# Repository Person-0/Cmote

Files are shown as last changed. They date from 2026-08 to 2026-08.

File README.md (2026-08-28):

# **Cmote**

A USB-C IR transmitter for controlling devices like ACs, TVs for when you're too lazy to find the remote and your smartphone does not have a built-in IR blaster. Built-in to a devboard powered by the Attiny1616 MCU.

# PCB
> View PCB Directory: [/PCB](./PCB)

Schematics:

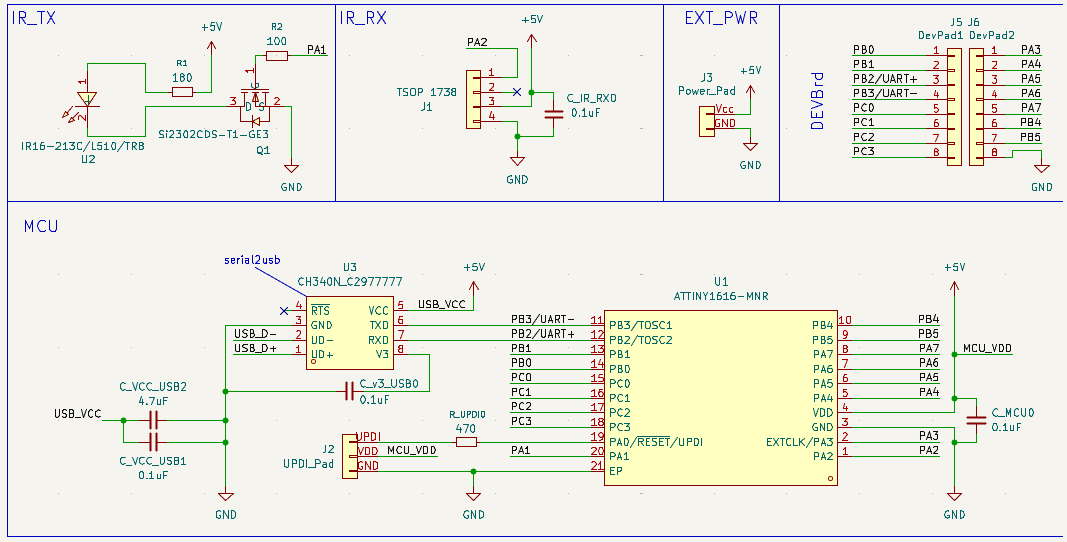
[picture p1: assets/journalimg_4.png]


PCB:

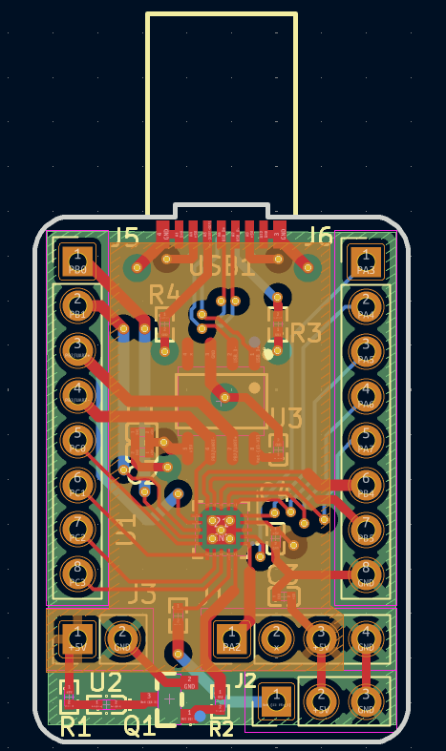
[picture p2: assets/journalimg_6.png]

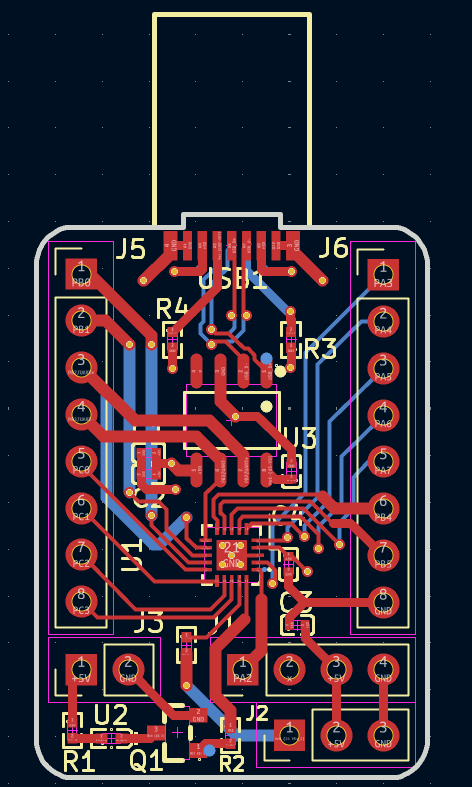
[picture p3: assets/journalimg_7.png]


Preview PCB 3D View:

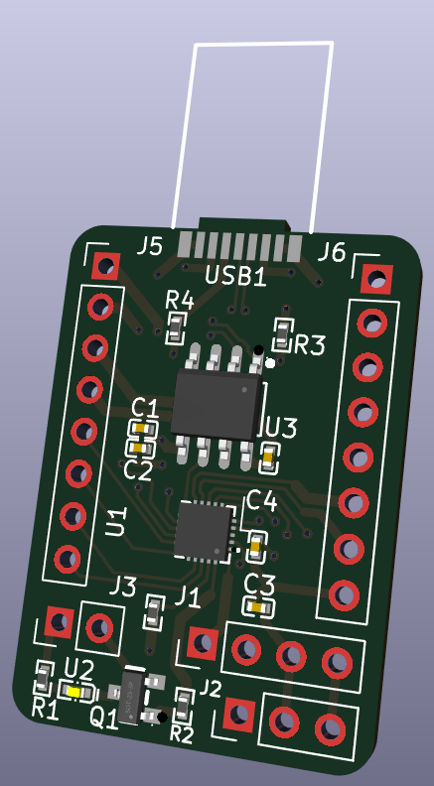
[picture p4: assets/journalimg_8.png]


Steps to open the schematics and PCB files in KiCAD:
- Open KiCAD
- Click **File** (top left) >> **Open Project**
- Navigate to this repository's saved destination,
- Open **/PCB/Cmote** directory
- Select the file `Cmote.kicad_pro`

This will open the schematics and PCB in KiCAD for easier viewing!

# Firmware
> View firmware directory: [/firmware](./firmware/)

> Note that firmware is Work In Progress. Until I physically receive the board I have no way of knowing whether this works or not so current it is just basic stuff.

The current firmware will send a power command at the start, listen to all the IR signals and print them to the serial on USB-C port of the board:

```cpp
bool sentPwrCmd = false;

void setup() {
	Serial.begin(115200); // serial is on usb-c
	IrSender.begin(IR_TX_PIN);
	IrReceiver.begin(IR_RX_PIN, ENABLE_LED_FEEDBACK); 
}

void loop() {

	if (!sentPwrCmd) {
		uint16_t address = 0x00; // standard device address
		uint8_t command = 0x45;  // standard power command
		IrSender.sendNEC(address, command, 0);
		sentPwrCmd = true;
		Serial.println("=== power command was sent!! ===");
	}

	if (IrReceiver.decode()) {
		Serial.println("-------------------------");
		Serial.println("\tbegin decode():");
        Serial.print("Protocol: ");
        Serial.println(getProtocolString(IrReceiver.decodedIRData.protocol));
        Serial.print("Command (Hex): 0x");
        Serial.println(IrReceiver.decodedIRData.command, HEX);
        Serial.print("Address (Hex): 0x");
        Serial.println(IrReceiver.decodedIRData.address, HEX);
        Serial.println("-------------------------\n");
        IrReceiver.resume(); 
    }

}
```

**IrReceiver and IrSender is from the [IRremote](https://registry.platformio.org/libraries/z3t0/IRremote) library.**

As for flashing the firmware onto the board, it requires a specialized UPDI programmer. However, I will be using another devboard to program this using **[pyupdi](https://github.com/mraardvark/pyupdi/)**. This guide will be updated after I test it myself to confirm what works and what does not.

# CAD
> View CAD Directory: [/CAD](./CAD)

While this is technically a devboard and has no requirement for a case, I still made one using Fusion360.

It looks like this:

> USB-C plug is invisible as no model was available for it from the manufacturer so I made sure to give enough space by measuring the silkscreen dimensions on the PCB and using it as the reference.

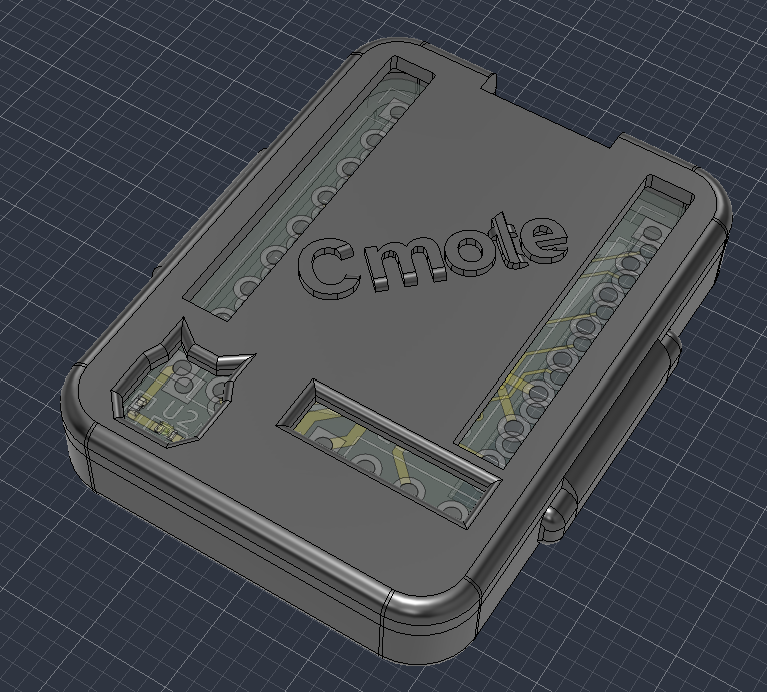
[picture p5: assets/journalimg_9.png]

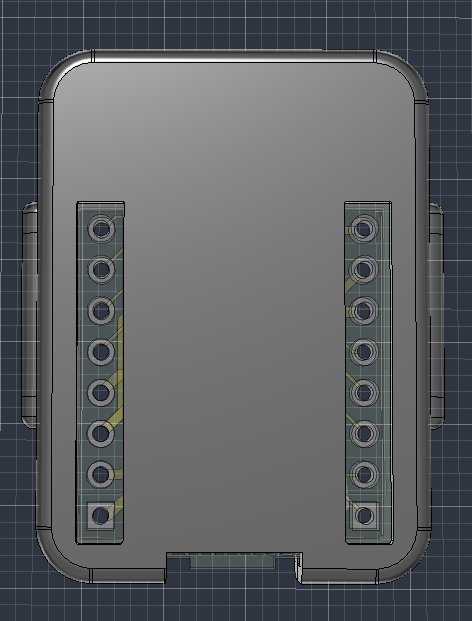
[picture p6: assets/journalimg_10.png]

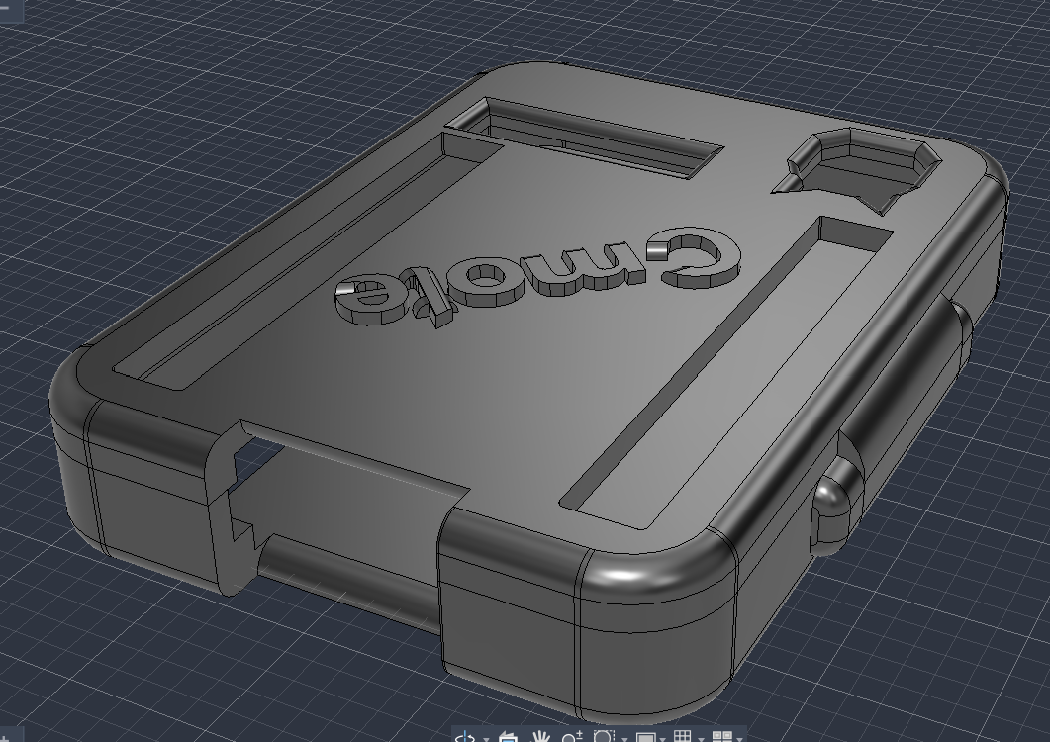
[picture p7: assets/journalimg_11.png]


The lid will friction fit into the case using the side extrusions.

It has rectangular cuts for headers so the devboard can be freely used without taking off the lid again and again.

**For 3d printing, files [Cmote_body.step](./CAD/Cmote_body.step) and [Cmote_lid.step](./CAD/Cmote_lid.step) need to be printed as different bodies.**

## Ordering Parts

I will be using JLCPCB to order my PCB as for my location it is the cheapest option (if using PCB Assembly service).

Please checkout the [JLC_Order](./PCB/JLC_Order/) directory for bom, cpl and gerber files.

The grand total for this project comes out to be at `42.24 USD`

- This is when I have used basic parts when possible and only 2 PCBA with 5 PCB (moq)

[View BOM](./bom.csv) <br>
[View PCBA BOM](./PCB/JLC_Order/pcb_bom.csv) <br>

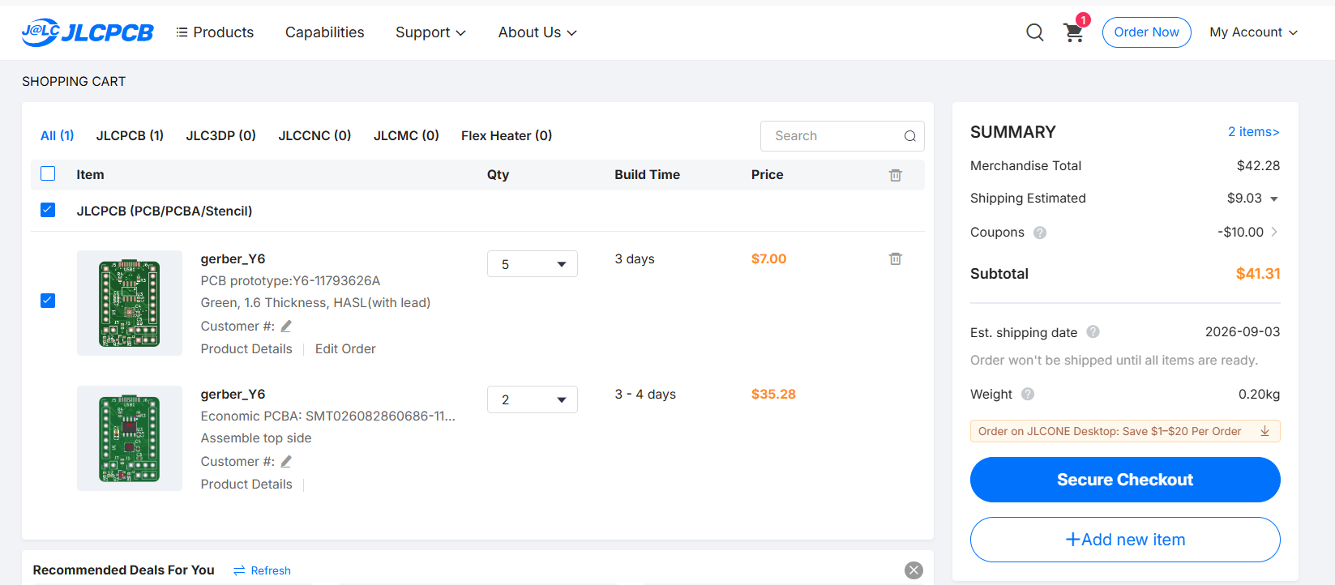
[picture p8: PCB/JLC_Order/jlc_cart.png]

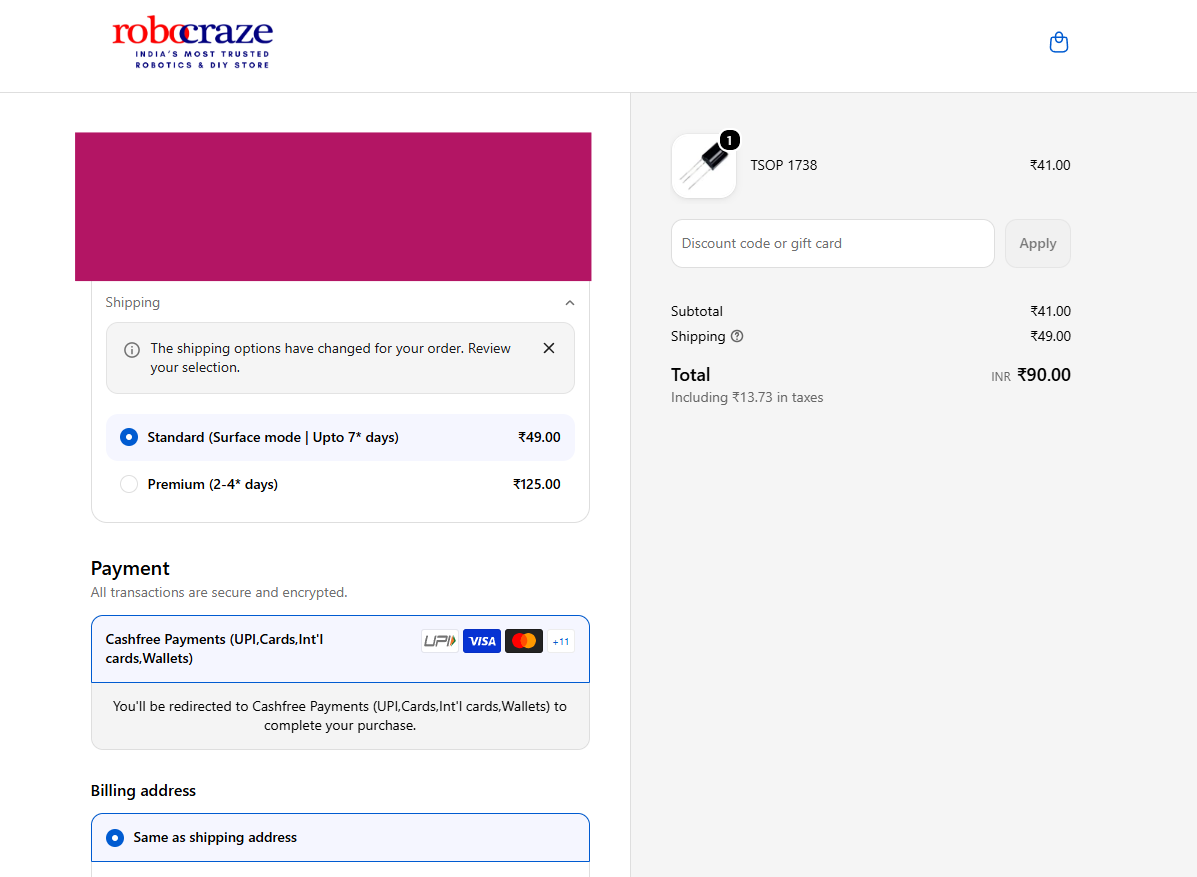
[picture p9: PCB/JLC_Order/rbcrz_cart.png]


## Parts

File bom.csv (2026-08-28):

 |  |  |  |  | $ | $
S.No | Name | Desc | Qty | Product URL | Cost Per Item | Effective Cost | Image
1 | JLCPCB_PCB | PCB | 1 | ~ | 7 | 7 | ./PCB/JLC_Order/jlc_cart.png
2 | JLCPCB_Assembly | PCB Assembly | 1 | ~ | 35.28 | 35.28
3 | JLCPCB_Shipping | Lowest price shipping: UPS Worldwide Express Saver | 1 | ~ | 9.03 | 9.03
4 | JLCPCB_Coupons | ~ | 1 | ~ | -10 | -10
5 | TSOP 1738 | IR Receiver Module | 1 | https://robocraze.com/products/tsop-1738?_pos=6&_sid=ae6cf2b3a&_ss=r | 0.43 | 0.43 | ./PCB/JLC_Order/rbcrz_cart.png
6 | Shipping for IR Receiver | Shipping for IR Receiver | 1 | https://robocraze.com/products/tsop-1738?_pos=6&_sid=ae6cf2b3a&_ss=r | 0.51 | 0.51
 |  |  |  |  | Total ($): | 42.25

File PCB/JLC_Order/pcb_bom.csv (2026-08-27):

Designator | Qty | Value | DNP | Exclude from BOM | Exclude from Board | Footprint | Datasheet | MPN | Manufacturer | LCSC Part | Description
C1 | 1 | 4.7uF |  |  |  | easyeda2kicad:C0402 | https://jlc-prod-smt.oss-eu-central-1.aliyuncs.com/smtDataManualFile/8579707103457972224-C19666.pdf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 | CL10A475KO8NNNC | Samsung Electro-Mechanics | C19666 | Unpolarized capacitor, small symbol
C2,C3,C4,C5 | 4 | 0.1uF |  |  |  | easyeda2kicad:C0402 | https://jlc-prod-smt.oss-eu-central-1.aliyuncs.com/smtDataManualFile/8579707269992677376-C1525.pdf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 | CL05B104KO5NNNC | Samsung Electro-Mechanics | C1525 | Unpolarized capacitor, small symbol
J1 | 1 | TSOP 1738 |  | Excluded from BOM |  | Connector_PinHeader_2.54mm:PinHeader_1x04_P2.54mm_Vertical | ~ |  |  |  | Generic connector, single row, 01x04, script generated (kicad-library-utils/schlib/autogen/connector/)
J2 | 1 | UPDI_Pad |  | Excluded from BOM |  | Connector_PinHeader_2.54mm:PinHeader_1x03_P2.54mm_Vertical | ~ |  |  |  | Generic connector, single row, 01x03, script generated (kicad-library-utils/schlib/autogen/connector/)
J3 | 1 | Power_Pad |  | Excluded from BOM |  | Connector_PinHeader_2.54mm:PinHeader_1x02_P2.54mm_Vertical | ~ |  |  |  | Generic connector, single row, 01x02, script generated (kicad-library-utils/schlib/autogen/connector/)
J5 | 1 | DevPad1 |  | Excluded from BOM |  | Connector_PinHeader_2.54mm:PinHeader_1x08_P2.54mm_Vertical | ~ |  |  |  | Generic connector, single row, 01x08, script generated (kicad-library-utils/schlib/autogen/connector/)
J6 | 1 | DevPad2 |  | Excluded from BOM |  | Connector_PinHeader_2.54mm:PinHeader_1x08_P2.54mm_Vertical | ~ |  |  |  | Generic connector, single row, 01x08, script generated (kicad-library-utils/schlib/autogen/connector/)
Q1 | 1 | Si2302CDS-T1-GE3 |  |  |  | easyeda2kicad:SOT-23_L2.9-W1.3-P1.90-LS2.4-BR | https://lcsc.com/product-detail/MOSFET_VISHAY_Si2302CDS-T1-GE3_Si2302CDS-T1-GE3_C10488.html | Si2302CDS-T1-GE3 | VISHAY(威世) | C10488 | Si2302CDS-T1-GE3
R1 | 1 | 180 |  |  |  | easyeda2kicad:R0402 | https://jlc-prod-smt.oss-eu-central-1.aliyuncs.com/smtDataManualFile/8755534832674197504-C137913.pdf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 | RC0402JR-07180RL | YAGEO | C137913 | Resistor, small symbol
R2 | 1 | 100 |  |  |  | easyeda2kicad:R0402 | https://jlc-prod-smt.oss-eu-central-1.aliyuncs.com/smtDataManualFile/8579705907476807680-C25076.pdf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 | 0402WGF1000TCE | UNI-ROYAL(Uniroyal Elec) | C25076 | Resistor, small symbol
R3,R4 | 2 | 5.1k |  |  |  | easyeda2kicad:R0402 | https://jlc-prod-smt.oss-eu-central-1.aliyuncs.com/smtDataManualFile/8579706035999215616-C25905.pdf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 | 0402WGF5101TCE | UNI-ROYAL(Uniroyal Elec) | C25905 | Resistor, small symbol
R_UPDI0 | 1 | 470 |  |  |  | easyeda2kicad:R0402 | https://jlc-prod-smt.oss-eu-central-1.aliyuncs.com/smtDataManualFile/8579705913225035776-C25117.pdf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 | 0402WGF4700TCE | UNI-ROYAL(Uniroyal Elec) | C25117 | Resistor, small symbol
U1 | 1 | ATTINY1616-MNR |  |  |  | easyeda2kicad:QFN-20_L3.0-W3.0-P0.40-BL-EP1.7 | https://lcsc.com/product-detail/MICROCHIP_Microchip-Tech-ATTINY1616-MNR_C507118.html | ATTINY1616-MNR | MICROCHIP(美国微芯) | C507118
U2 | 1 | IR16-213C/L510/TR8 |  |  |  | easyeda2kicad:LED0402-FD_YELLOW | https://www.lcsc.com/datasheet/C2943465.pdf | IR16-213C/L510/TR8 | EVERLIGHT(亿光) | C2943465
U3 | 1 | CH340N_C2977777 |  |  |  | easyeda2kicad:SOP-8_L4.9-W3.9-P1.27-LS6.0-BL | https://www.lcsc.com/datasheet/C2977777.pdf | CH340N | WCH(南京沁恒) | C2977777
USB1 | 1 | HYCW671-USBC14-115B |  |  |  | easyeda2kicad:USB-SMD_HYCW671-USBC14-115B | https://www.lcsc.com/datasheet/C53436581.pdf | HYCW671-USBC14-115B | HOAUC(华宇创) | C53436581

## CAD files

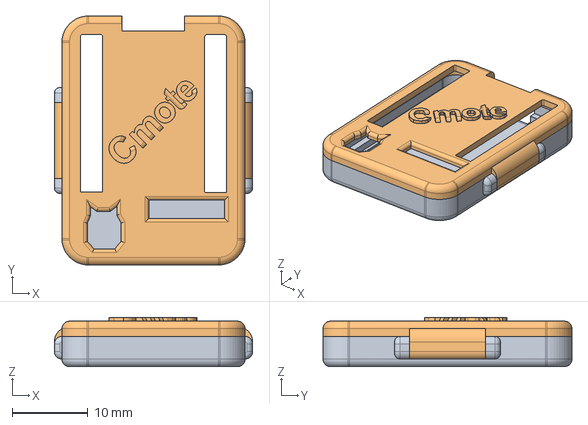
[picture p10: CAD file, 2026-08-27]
CAD/Cmote_full_DoNotPrint.step
26.2 x 32.9 x 6.50 mm

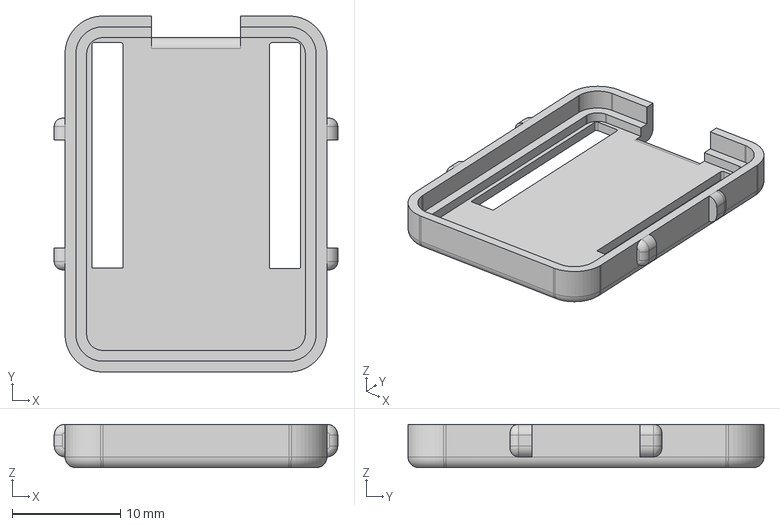
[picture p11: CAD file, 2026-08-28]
CAD/Cmote_body.step
26.2 x 32.9 x 4.00 mm

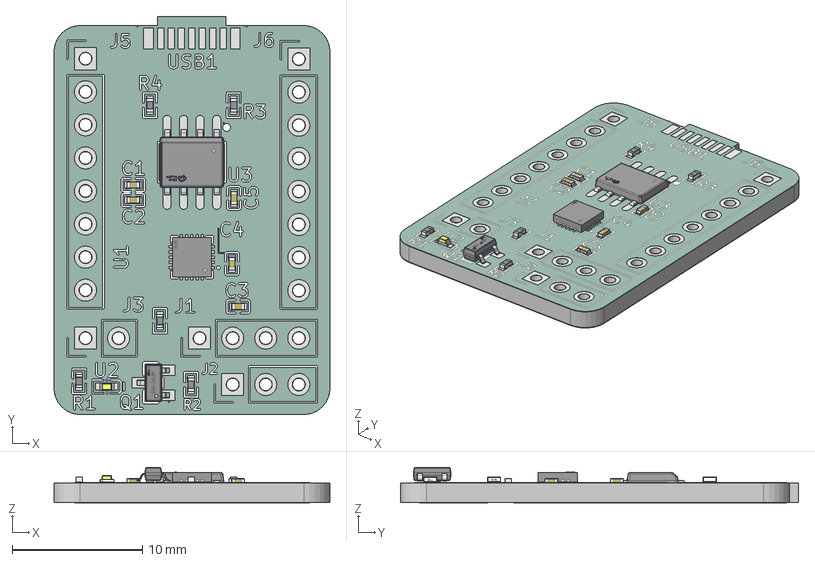
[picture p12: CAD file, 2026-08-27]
CAD/models/CmotePCB.step
21.2 x 30.6 x 2.77 mm
LED0402-FD_YELLOW
C0402_L1.0-W0.5-H0.5 x 5
R0402_L1.0-W0.5-H0.4 x 5
QFN-20_L3.0-W3.0-P0.40-BL-EP1.7
SOP-8_L4.9-W3.9-P1.27-LS6.0-BL-1
SOT-23-3P_L2.9-W1.3-H1.0-LS2.4-P0.95
Cmote_copper
Cmote_pad
Cmote_via
Cmote_silkscreen x 2
Cmote_soldermask x 2
Cmote_PCB

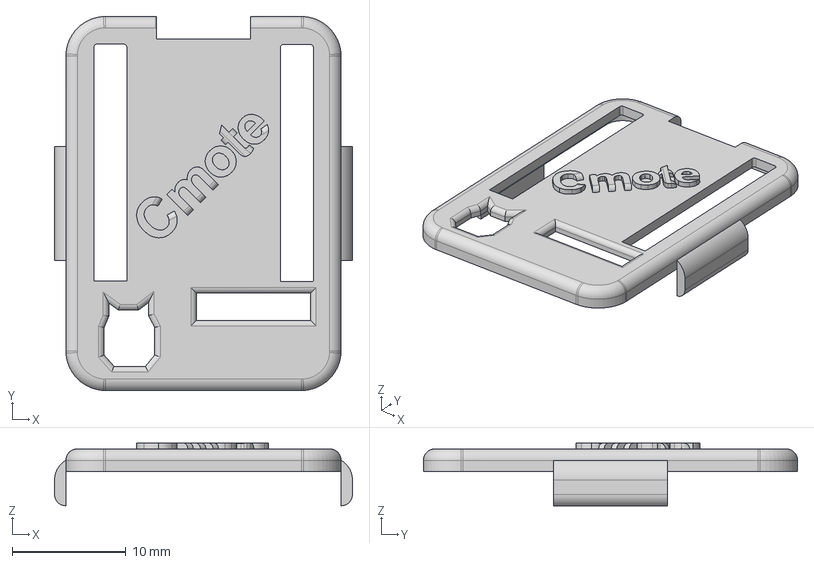
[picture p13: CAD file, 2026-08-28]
CAD/Cmote_lid.step
26.2 x 32.9 x 5.50 mm

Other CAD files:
CAD/Cmote.f3d

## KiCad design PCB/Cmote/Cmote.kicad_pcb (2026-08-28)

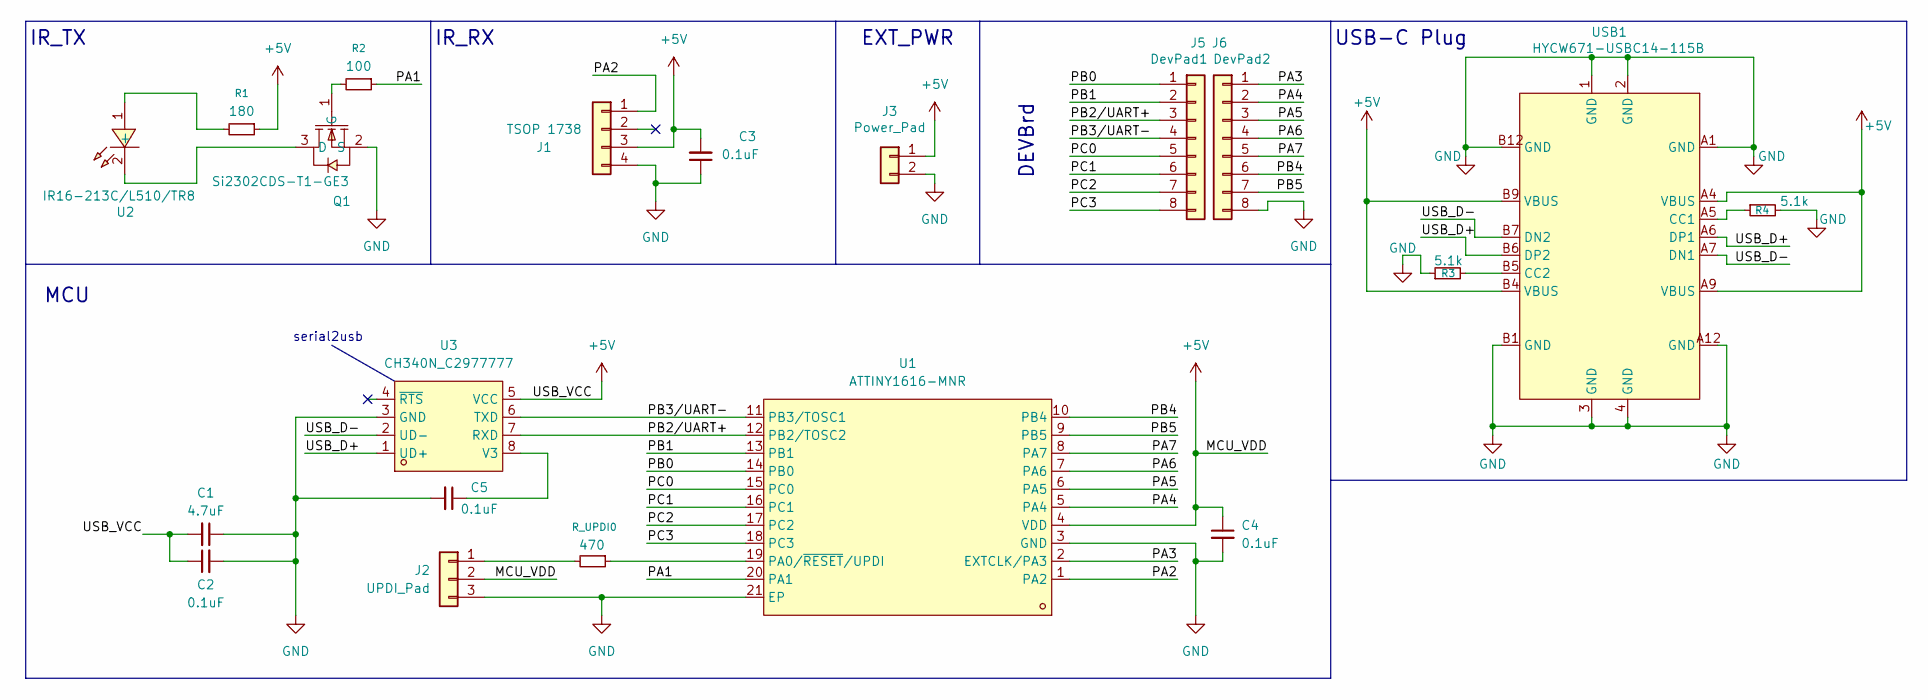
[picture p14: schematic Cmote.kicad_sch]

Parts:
C1: 4.7uF; C0402; MPN CL10A475KO8NNNC; LCSC Part C19666
C2, C3, C4, C5: 0.1uF; C0402; MPN CL05B104KO5NNNC; LCSC Part C1525
J1: TSOP 1738; PinHeader_1x04_P2.54mm_Vertical
J2: UPDI_Pad; PinHeader_1x03_P2.54mm_Vertical
J3: Power_Pad; PinHeader_1x02_P2.54mm_Vertical
J5: DevPad1; PinHeader_1x08_P2.54mm_Vertical
J6: DevPad2; PinHeader_1x08_P2.54mm_Vertical
Q1: Si2302CDS-T1-GE3; SOT-23_L2.9-W1.3-P1.90-LS2.4-BR; MPN Si2302CDS-T1-GE3; LCSC Part C10488
R1: 180; R0402; MPN RC0402JR-07180RL; LCSC Part C137913
R2: 100; R0402; MPN 0402WGF1000TCE; LCSC Part C25076
R3, R4: 5.1k; R0402; MPN 0402WGF5101TCE; LCSC Part C25905
R_UPDI0: 470; R0402; MPN 0402WGF4700TCE; LCSC Part C25117
U1: ATTINY1616-MNR; QFN-20_L3.0-W3.0-P0.40-BL-EP1.7; MPN ATTINY1616-MNR; LCSC Part C507118
U2: IR16-213C/L510/TR8; LED0402-FD_YELLOW; MPN IR16-213C/L510/TR8; LCSC Part C2943465
U3: CH340N_C2977777; SOP-8_L4.9-W3.9-P1.27-LS6.0-BL; MPN CH340N; LCSC Part C2977777
USB1: HYCW671-USBC14-115B; USB-SMD_HYCW671-USBC14-115B; MPN HYCW671-USBC14-115B; LCSC Part C53436581

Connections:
+5V: C1.2, C2.1, C3.2, C4.1, J1.3, J2.2, J3.1, R1.1, U1.4 (VDD), U3.5 (VCC), USB1.A4 (VBUS), USB1.A9 (VBUS), USB1.B4 (VBUS), USB1.B9 (VBUS)
/PA1: R2.1, U1.20 (PA1)
/PA2: J1.1, U1.1 (PA2)
/PA3: J6.1, U1.2 (EXTCLK/PA3)
/PA4: J6.2, U1.5 (PA4)
/PA5: J6.3, U1.6 (PA5)
/PA6: J6.4, U1.7 (PA6)
/PA7: J6.5, U1.8 (PA7)
/PB0: J5.1, U1.14 (PB0)
/PB1: J5.2, U1.13 (PB1)
/PB2/UART+: J5.3, U1.12 (PB2/TOSC2), U3.7 (RXD)
/PB3/UART-: J5.4, U1.11 (PB3/TOSC1), U3.6 (TXD)
/PB4: J6.6, U1.10 (PB4)
/PB5: J6.7, U1.9 (PB5)
/PC0: J5.5, U1.15 (PC0)
/PC1: J5.6, U1.16 (PC1)
/PC2: J5.7, U1.17 (PC2)
/PC3: J5.8, U1.18 (PC3)
/USB_D+: U3.1 (UD+), USB1.A6 (DP1), USB1.B6 (DP2)
/USB_D-: U3.2 (UD-), USB1.A7 (DN1), USB1.B7 (DN2)
GND: C1.1, C2.2, C3.1, C4.2, C5.2, J1.4, J2.3, J3.2, J6.8, Q1.2 (S), R3.1, R4.2, U1.3 (GND), U1.21 (EP), U3.3 (GND), USB1.1 (GND), USB1.2 (GND), USB1.3 (GND), USB1.4 (GND), USB1.A1 (GND), USB1.A12 (GND), USB1.B1 (GND), USB1.B12 (GND)
unnamed: J2.1, R_UPDI0.2
unnamed: Q1.3 (D), U2.2 (-)
unnamed: Q1.1 (G), R2.2
unnamed: R_UPDI0.1, U1.19 (PA0/~RESET/UPDI)
unnamed: R1.2, U2.1 (+)
unnamed: C5.1, U3.8 (V3)
unnamed: R4.1, USB1.A5 (CC1)
unnamed: R3.2, USB1.B5 (CC2)

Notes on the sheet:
EXT_PWR
IR_TX
serial2usb
USB-C Plug
MCU
DEVBrd
IR_RX

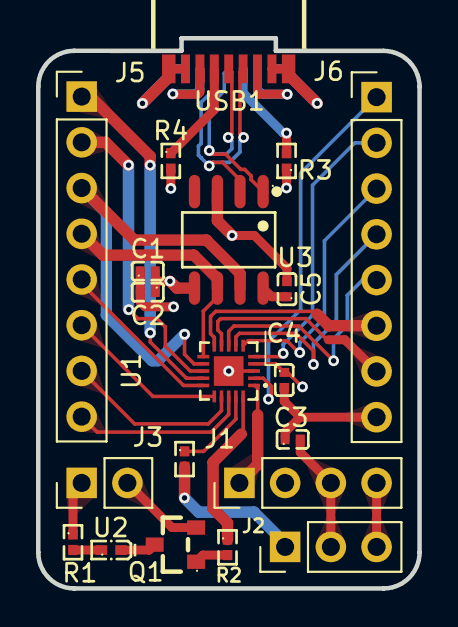
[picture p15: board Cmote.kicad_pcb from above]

Board: 4 copper layers, 21.2 x 30.6 mm, 20 parts (0 on the bottom side), 29 nets.

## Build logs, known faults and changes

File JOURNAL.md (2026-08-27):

# **Cmote**

A USB-C IR transmitter for controlling devices like ACs, TVs for when you're too lazy to find the remote and your smartphone does not have a built-in IR blaster. Built-in to a devboard powered by the Attiny1616 MCU.

Time Spent: `13h`

---
---
### `(#01)` 26/08/26 (22:39)
## Beginning: 1h

This is the start of Cmote!<br>
I researched about the components that will be required to make this and added them to my schematics in KiCAD.<br>
The PCB files are available in the [PCB directory](./PCB/).

I settled upon using the ATtiny1616 microcontroller as it is small, capable enough, has hardware timers and consumes very less power while working directly with 5V logic level.

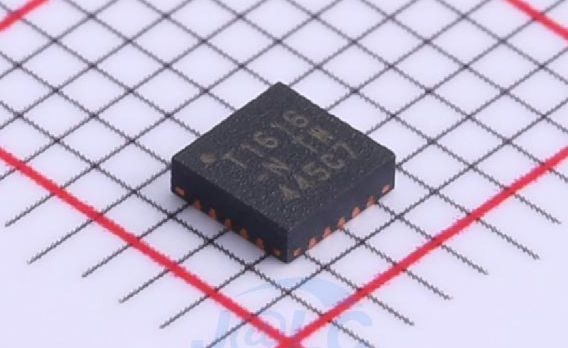
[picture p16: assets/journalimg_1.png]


<br>

For transmitting the IR signals, I settled upon using this `Infrared LED Emitter` I found on JLC which will be soldered to the PCB directly and is a small 0402 package: [link](https://jlcpcb.com/partdetail/EverlightElec-IR16_213C_L510TR8/C2943465). It supports 5V at 940nm wavelength which is extremely common in IR devices.

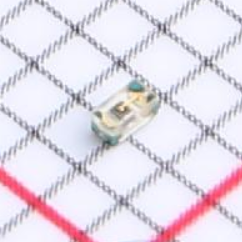
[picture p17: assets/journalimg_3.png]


I will be using this with a Si2302 mosfet to properly drive it as driving it directly from the MCU is never a good idea.
<br>

For receiving the IR signals I settled upon using `TSOP 1738` as it consists of a PIN diode and a preamplifier which are embedded into a single package ([source](https://robocraze.com/products/tsop-1738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.)).

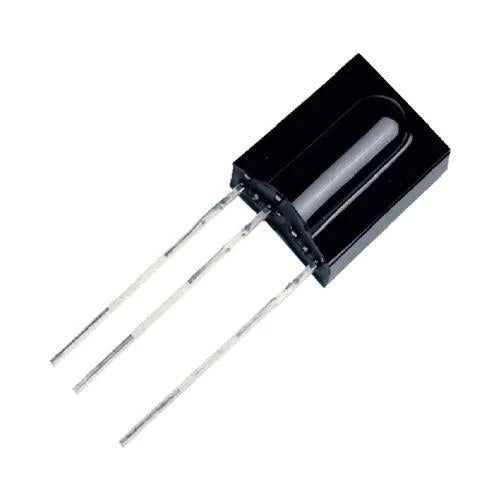
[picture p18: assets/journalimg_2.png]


<br>

Other than that, I setup this GitHub repository with the `README.md` and `JOURNAL.md` files with a clean directory structure for easier management of this project.

---
---
### `(#02)` 27/08/26 (02:03)
## Schematics, BOM: 3h

I connected all the components together by looking at their individual datahsheets and keeping in mind the voltage levels and tolerances along with stuff like bypass, decoupling capacitors that were mentioned in the datasheets.

For the Attiny1616, I added a CH340N to convert serial to USB signals which will allow us to communicate with our device over a USB port.

I haven't added the USB plug yet, that is for the next journal.

I added 2.54mm header pads for the following:
- Power (+5V, GND)
- UPDI Programming (VDD, GND, UPDI)
- 2x 8pin unused MCU Pins (7 pins, 1 GND)



---
---
### `(#03)` 27/08/26 (05:39)
## USB-C, PCB: 5h

I completed the schematics including the USB-C Plug

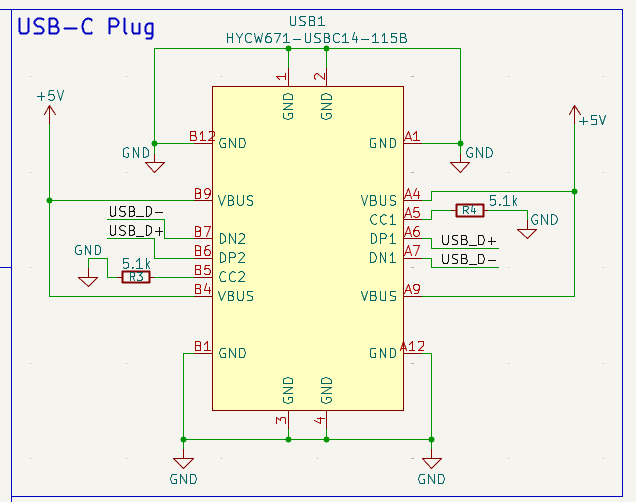
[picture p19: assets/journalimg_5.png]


I used [this](https://www.lcsc.com/product-detail/C53436568.html) USB-C plug from JLCPCB, and it extremely hard to find a side-mount USB-C plug that supported economic assembly (standard assembly costs too much)

I finished routing the PCB and made sure the decoupling capacitors were as close to the appropriate pin as possible and routed the USB D+ and D- as differential pairs to ensure signal integrity.

The PCB is a 4-layer stackup:
- Layer 1: Top F.Cu (signal traces)
- Layer 2: In1.Cu (ground plane)
- Layer 3: In2.Cu (power plane)
- Layer 4: Bottom B.Cu (signal traces)

The finished routed PCB looks like this:




Preview PCB 3D View:



Note that this board has no "reset button" as it will be programmed using the UPDI header pad (extreme bottom right) which does not require a reset button. As for programming the board, it requires a specialized UPDI programmer BUT i will be using another devboard to program this using [pyupdi](https://github.com/mraardvark/pyupdi/).

---
---
### `(#04)` 28/08/26 (03:03)
## CAD: 4h

While this is technically a devboard and has no requirement for a case, I still made one using Fusion360.

It looks like this:





The lid will friction fit into the case using the side extrusions.

It has rectangular cuts for headers so the devboard can be freely used without taking off the lid again and again.

---
---
### `(#05)` 28/08/26 (04:15)
## Firmware: 1h

I implemented basic firmware for sending a power command using the IR led and also receiving IR data from the TSOP 1738.

I used VSCode with the PlatformIO extension to speed up the dev process and ensured that the project built successfully. Now the only thing remaining is testing whether it actually works in real life and then I can move on the completing the actual firmware.

The current firmware (located in [/firmware/cmote/](./firmware/cmote/)) is this:

```cpp
bool sentPwrCmd = false;

void setup() {
	Serial.begin(115200); // serial is on usb-c
	IrSender.begin(IR_TX_PIN);
	IrReceiver.begin(IR_RX_PIN, ENABLE_LED_FEEDBACK); 
}

void loop() {

	if (!sentPwrCmd) {
		uint16_t address = 0x00; // standard device address
		uint8_t command = 0x45;  // standard power command
		IrSender.sendNEC(address, command, 0);
		sentPwrCmd = true;
		Serial.println("=== power command was sent!! ===");
	}

	if (IrReceiver.decode()) {
		Serial.println("-------------------------");
		Serial.println("\tbegin decode():");
        Serial.print("Protocol: ");
        Serial.println(getProtocolString(IrReceiver.decodedIRData.protocol));
        Serial.print("Command (Hex): 0x");
        Serial.println(IrReceiver.decodedIRData.command, HEX);
        Serial.print("Address (Hex): 0x");
        Serial.println(IrReceiver.decodedIRData.address, HEX);
        Serial.println("-------------------------\n");
        IrReceiver.resume(); 
    }

}
```

It will send a power command at the start and then just listen to all the IR signals and print them to the serial on USB-C port of the board.

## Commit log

2026-08-27 pcb done
    [Cmote.kicad_pcb, Cmote.kicad_sch]
2026-08-27 silkscreen "art"
    [Cmote.kicad_pcb, Cmote.kicad_sch]
2026-08-27 cad completed
    [Cmote.f3d, Cmote.kicad_pcb, Cmote.step]
2026-08-27 rename models/Cmote.step as it is the PCB model not the case
    [CmotePCB.step]
2026-08-27 updated parts to get more basic assembly
    [Cmote.kicad_sch]
2026-08-27 added jlc order fiels and outer bom
    [bom.csv, pcb_bom.csv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]
2026-08-27 added image links
    [bom.csv]
2026-08-28 add 3d printing info
    [Cmote_body.step, Cmote_full_DoNotPrint.step, Cmote_lid.step]
2026-08-28 update via to prevent solder wicking
    [Cmote.kicad_pcb, bom.csv]
